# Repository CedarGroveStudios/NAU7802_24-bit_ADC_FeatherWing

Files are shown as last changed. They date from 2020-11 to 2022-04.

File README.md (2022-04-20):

# NAU7802_24-bit_ADC_FeatherWing

### Custom 24-bit load cell sensor ADC with dual analog inputs powered by CircuitPython.

[NAU7802 CircuitPython Driver: Class Description](https://github.com/CedarGroveStudios/NAU7802_24-bit_ADC_FeatherWing/blob/main/docs/pseudo%20readthedocs%20cedargrove_nau7802.pdf)

NAU7802 FeatherWing 16-SOIC (SMD) Version:



NAU7802 FeatherWing  16-DIP (THT) Version:



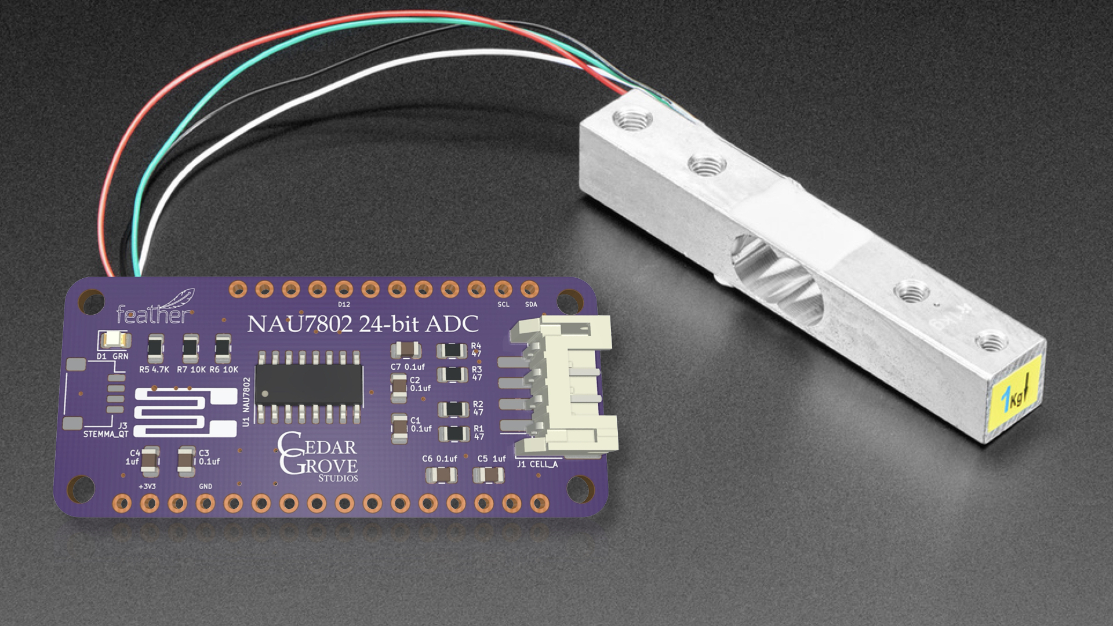
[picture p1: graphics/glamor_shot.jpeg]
NAU7802 FeatherWing


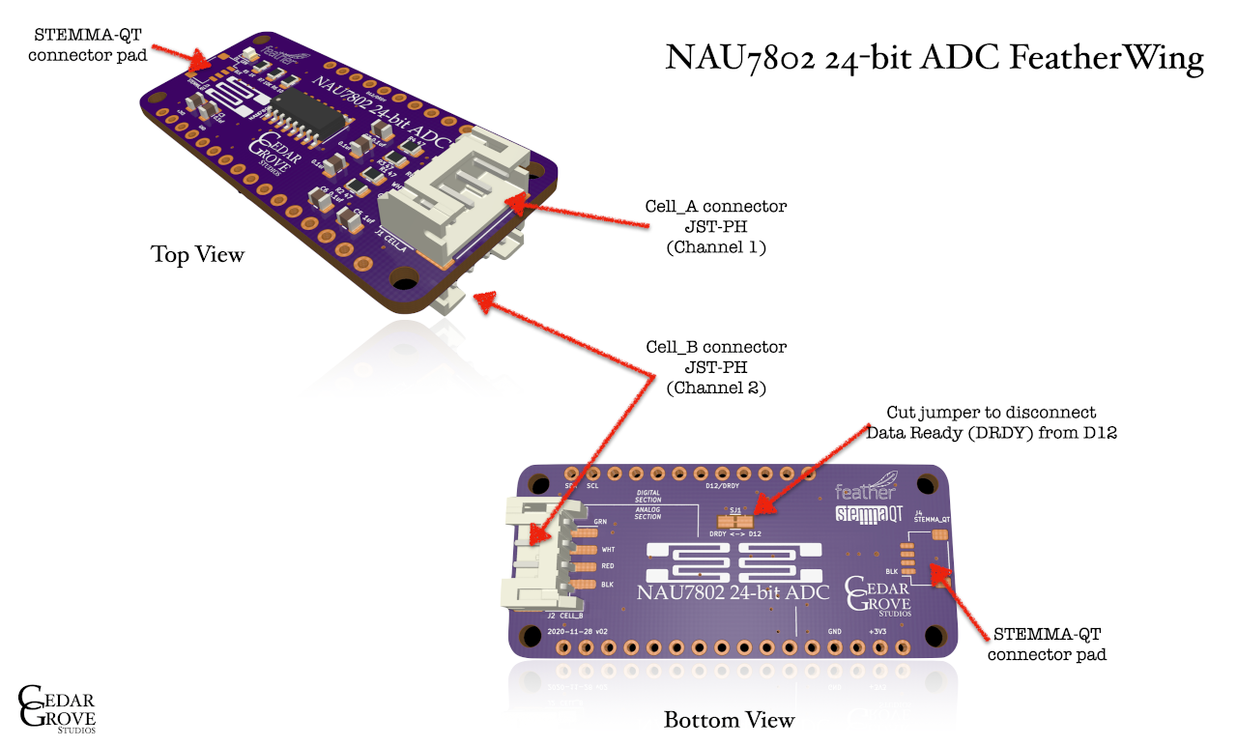
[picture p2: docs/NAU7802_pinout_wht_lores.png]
NAU7802 FeatherWing pinout


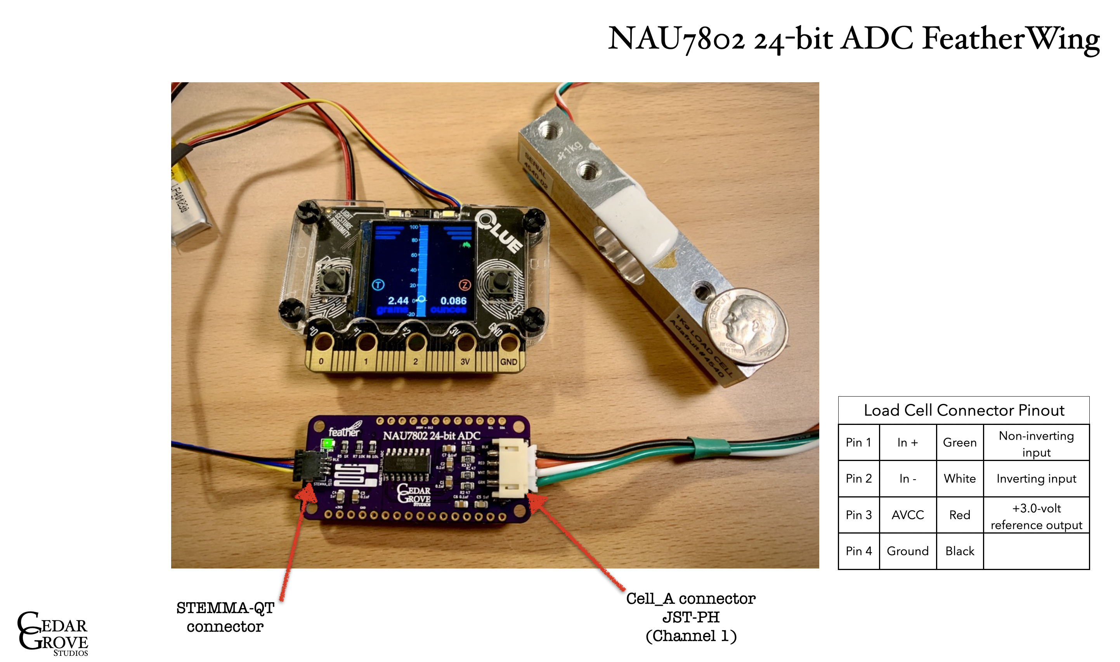
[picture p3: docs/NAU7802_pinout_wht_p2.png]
NAU7802 cable pinout


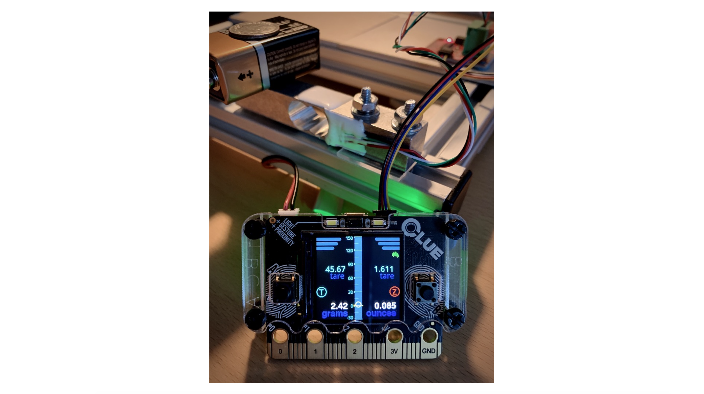
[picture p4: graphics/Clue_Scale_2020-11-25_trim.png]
Clue_Scale


Needing a calibration weight? The U.S. Mint coin specifications might have some information that could help -- if you have some spare change. https://www.usmint.gov/learn/coin-and-medal-programs/coin-specifications

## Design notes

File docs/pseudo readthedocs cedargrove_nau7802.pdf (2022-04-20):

## cedargrove_nau7802

A CircuitPython class for operating the Cedar Grove NAU7802 24-bit ADC load cell sensor FeatherWing.

The Cedar Grove NAU7802 FeatherWing is a high-precision 24-bit ADC with analog inputs designed for load cell Wheatstone bridge differential signals. The FeatherWing accepts input from up to two load cells, providing gain management, reference voltage selection, and channel calibration/offset functions. Applications include a variety of mass measurement and calculation devices from simple weighing scales to motor rotary torque calculations.

- Author(s): JG Cedar Grove Maker Studios

## Implementation Notes

### Hardware: Software and Dependencies:

- Adafruit CircuitPython firmware for the supported boards: https://github.com/adafruit/circuitpython/releases

Class representing the CedarGroveMaker NAU7802.

The primary function of the NAU7802 class. The read() function captures the latest 24-bit data acquired, sets the ADC data-availability status to False, and returns a signed integer value. The read() function does not check the ADC data-available status nor does it initiate a data acquisition cycle.

Determines the ADC data-availability status. Returns True when new data is available to read. The available() function does not initiate a data acquisition cycle.

class cedargrove_nau7802.NAU7802(*, i2c_bus, address=0x2A, active_channels=1)

Parameters: | • | i2c_bus – The I2C data and clock bus signals as defined in the host device’s board definition. Typical value is board.I2C() . No default value.
- address – The I2C bus address. Defaults to 0x2A (d42).
- active_channels – The maximum number of active analog differential input channels
| | used. The Cedar Grove NAU7802 FeatherWing supports either one or two input channels. Can only be a positive integer with a value of 1 or 2. Defaults to 1.

read()

available()

© Copyright 2021, 2022 Cedar Grove Maker Studios, Revision 1.3

Enable(start) or disable(stop) the internal analog and digital systems power. The device enters a low-power standby mode when disabled but preserves calibration information and maintains I2C communications. The device commences a 750msec power-up cycle when power=True and starts the acquisition cycle. The device will initiate a 10msec shutdown process when power=False. Returns True when power is enabled; False when disabled.

Perform the calibration procedure. Valid calibration modes are ‘INTERNAL’, ‘OFFSET’, and ‘GAIN’. Returns True if the calibration process was successful; False if an error occurred. For sensitive applications, calibration is recommended whenever the input channel is changed or when ambient conditions may cause measurement drift.

Resets all internal device registers and enables digital system power. Returns the power ready status Boolean value: True when the device is ready; False if not ready. All device registers are reset to the NAU7802 default settings including calibration offset and gain settings. It is not usually necessary to use the reset() function since it is executed as part of the class initialization process.

enable(power=True)

Parameters: | power – The power enable/disable state. Accepts a True or False Boolean value. Defaults to True (enable power).

calibrate(mode=‘INTERNAL’)

Parameters: | mode – The device calibration process to initiate. The following string values are accepted:
| ‘INTERNAL’ — Ignore analog input signals and calibrate the the input offset using an internal reference voltage. This is the default calibration setting.
| ‘OFFSET’ — Measure and store the external analog input offset for the selected channel. Analog input signals must be held at a zero input value during external offset calibration. Useful for determining the zero offset of an attached load cell bridge.
| ‘GAIN’ — Measure and store the external gain setting of the selected channel required for full-scale. Analog input signals must be held at the equivalent full- scale value during external gain calibration. Useful for determining the gain needed to calibrate a weighted load cell at its maximum sensor range.

reset()

A class property.

A class property.

A class property.

channel

Parameters: | channel – Change or read the numeric value of the currently selected external analog input channel. Valid external input channel numeric values are 1 or 2 representing the NAU7802 FeatherWing’s CELL_A and CELL_B, respectively. Selection of the second input channel requires active_channels=2 when the class is instantiated. The channel property defaults to 1.

ldo_voltage

Parameters: | ldo_voltage – Change or read the representative value of the currently selected internal low-dropout (LDO) regulator’s analog power and conversion reference voltage (AVCC). Digital supply voltage (DVCC) must be at least 0.3 volts greater than the selected ldo_voltage value. Valid string values are ‘2V4’, ‘2V7’, and ‘3V0’, representing 2.4, 2.7, and 3.0 volts. Defaults to ‘3V0’.

gain

Parameters: | gain – Change or read the value of the currently selected programmable gain amplifier (PGA) gain setting. Valid numeric values are 1, 2, 4, 8, 16, 31, 64, and 128. Defaults to
| 128.

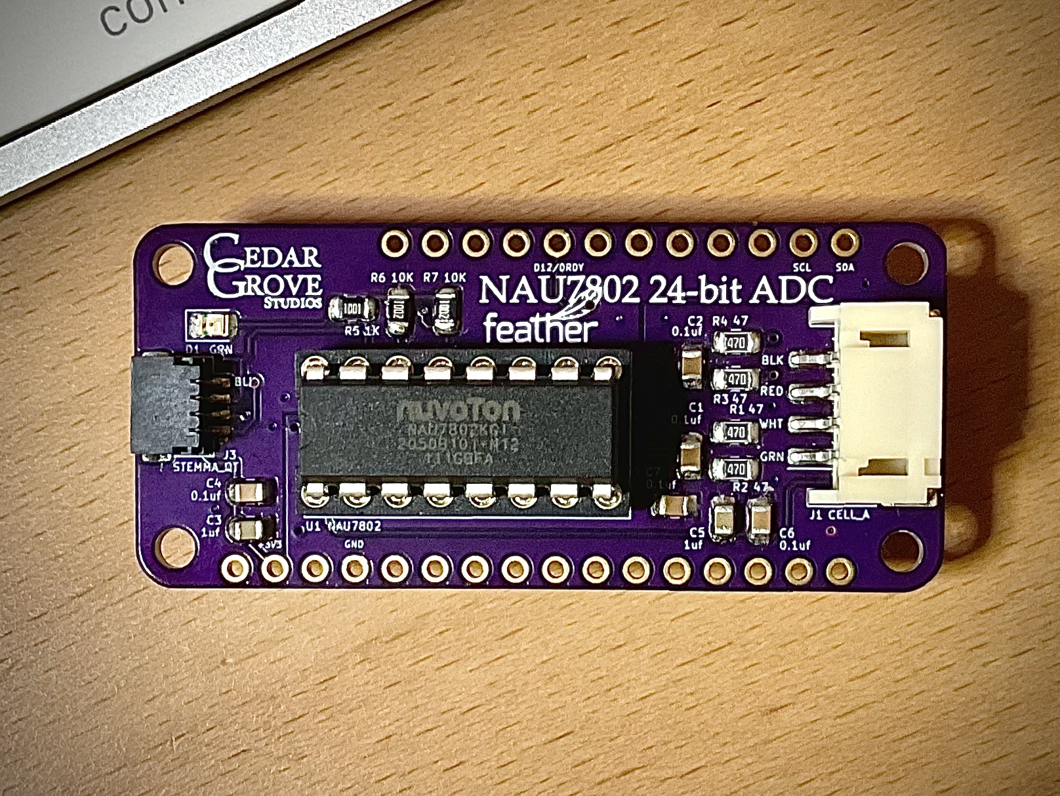
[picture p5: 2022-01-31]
docs/CG_NAU7802_FeatherWing_16-DIP.png

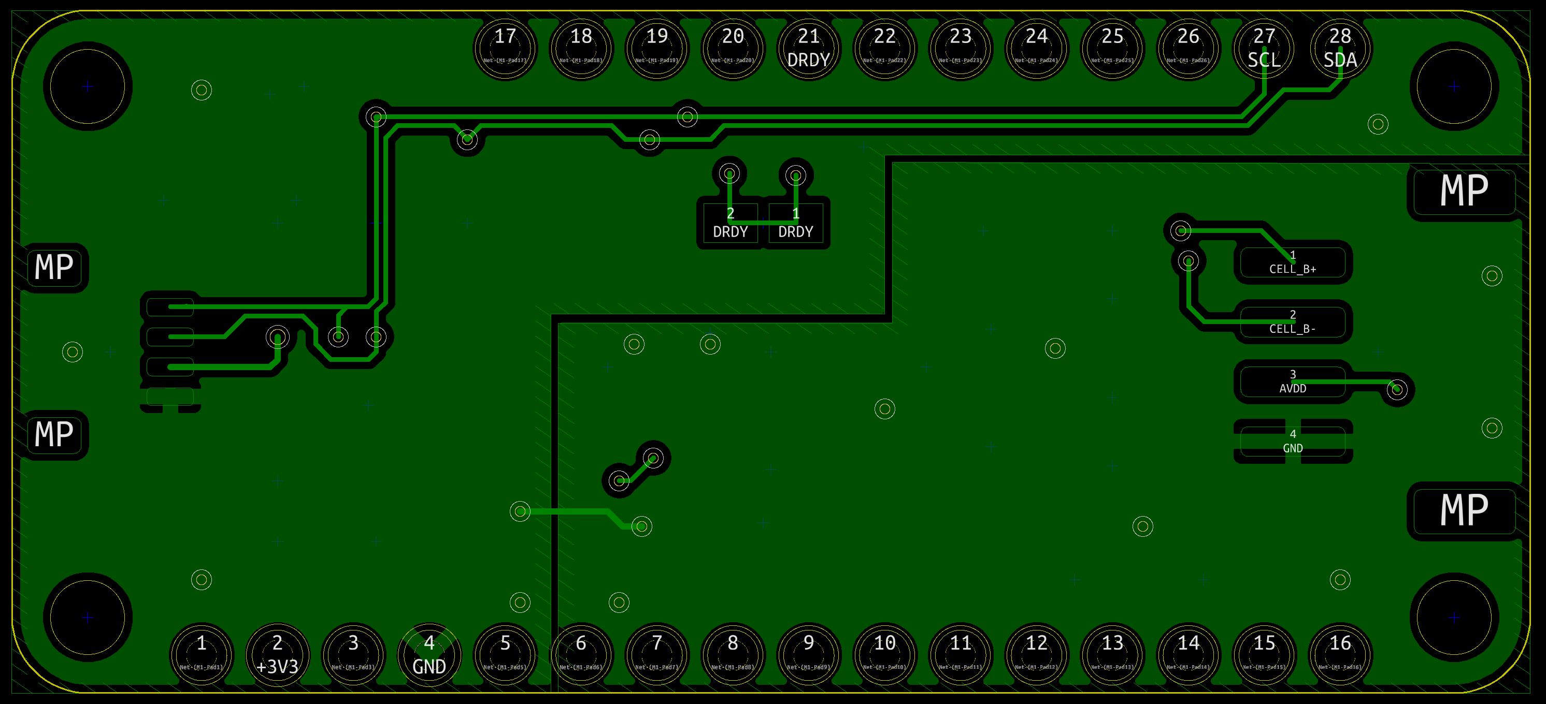
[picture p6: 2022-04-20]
pcb/pcb_bottom_copper.png

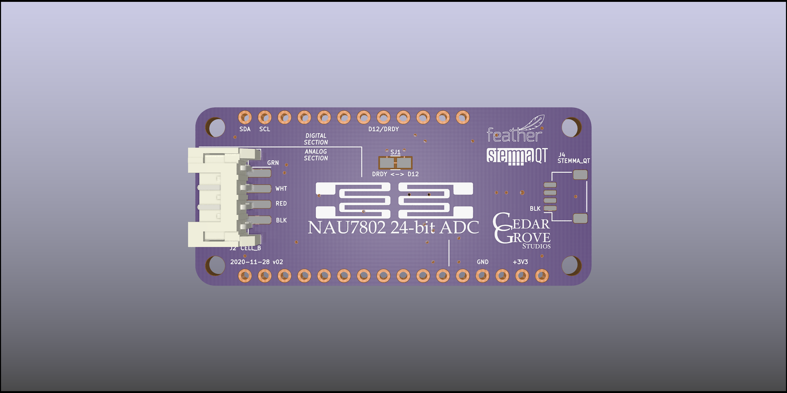
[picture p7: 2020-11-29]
pcb_DIP/NAU7802_Dual_24-bit_ADC_bot.png

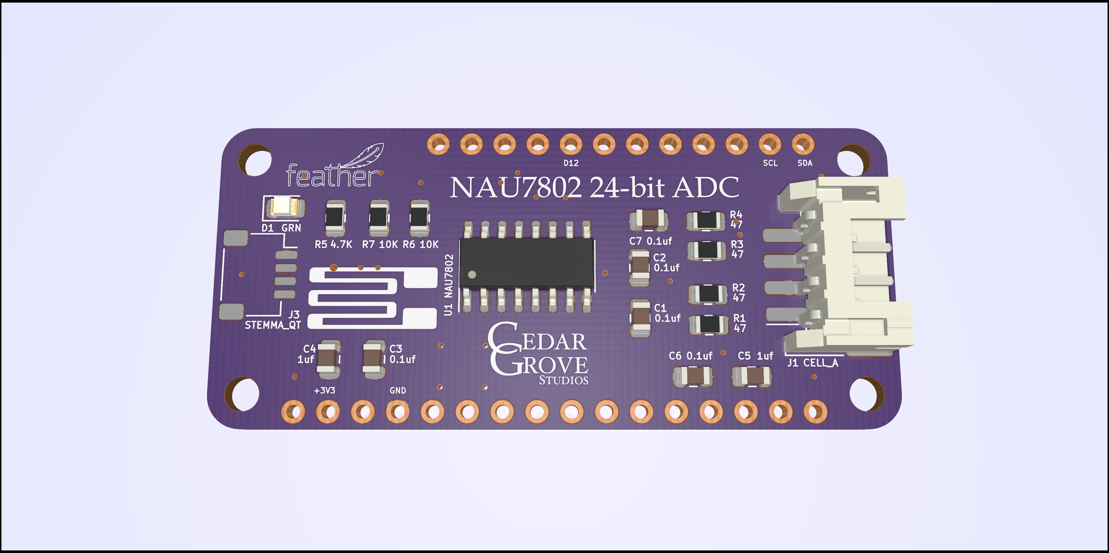
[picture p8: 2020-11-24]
graphics/NAU7802_Dual_24-bit_ADC.png

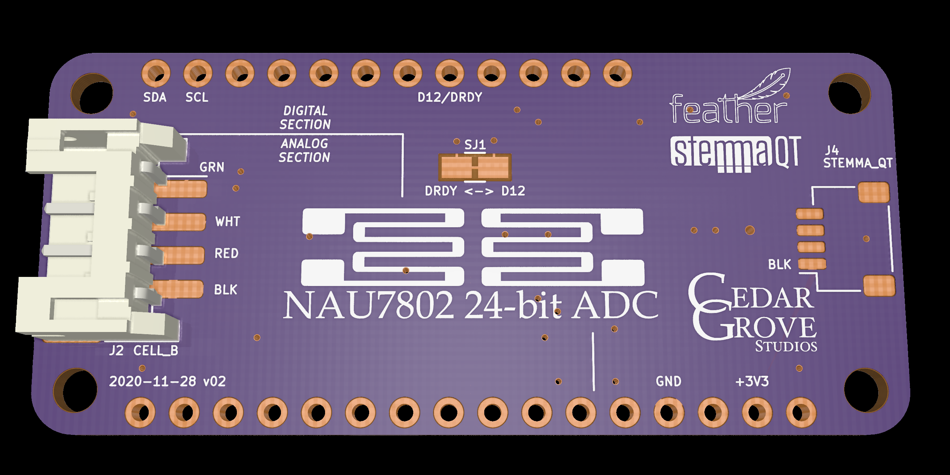
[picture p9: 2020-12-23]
graphics/NAU7802_Dual_24-bit_ADC_anno_2.png

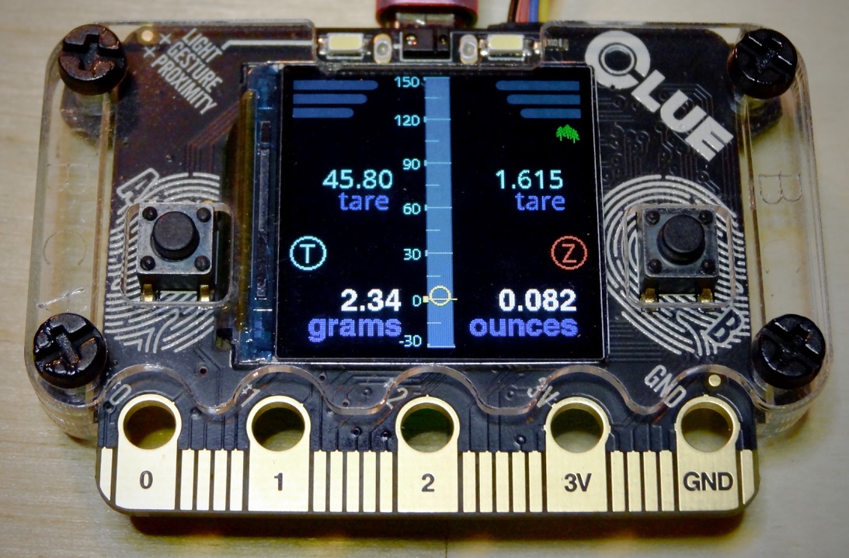
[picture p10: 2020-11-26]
graphics/Clue_Scale_2020-11-25.jpeg

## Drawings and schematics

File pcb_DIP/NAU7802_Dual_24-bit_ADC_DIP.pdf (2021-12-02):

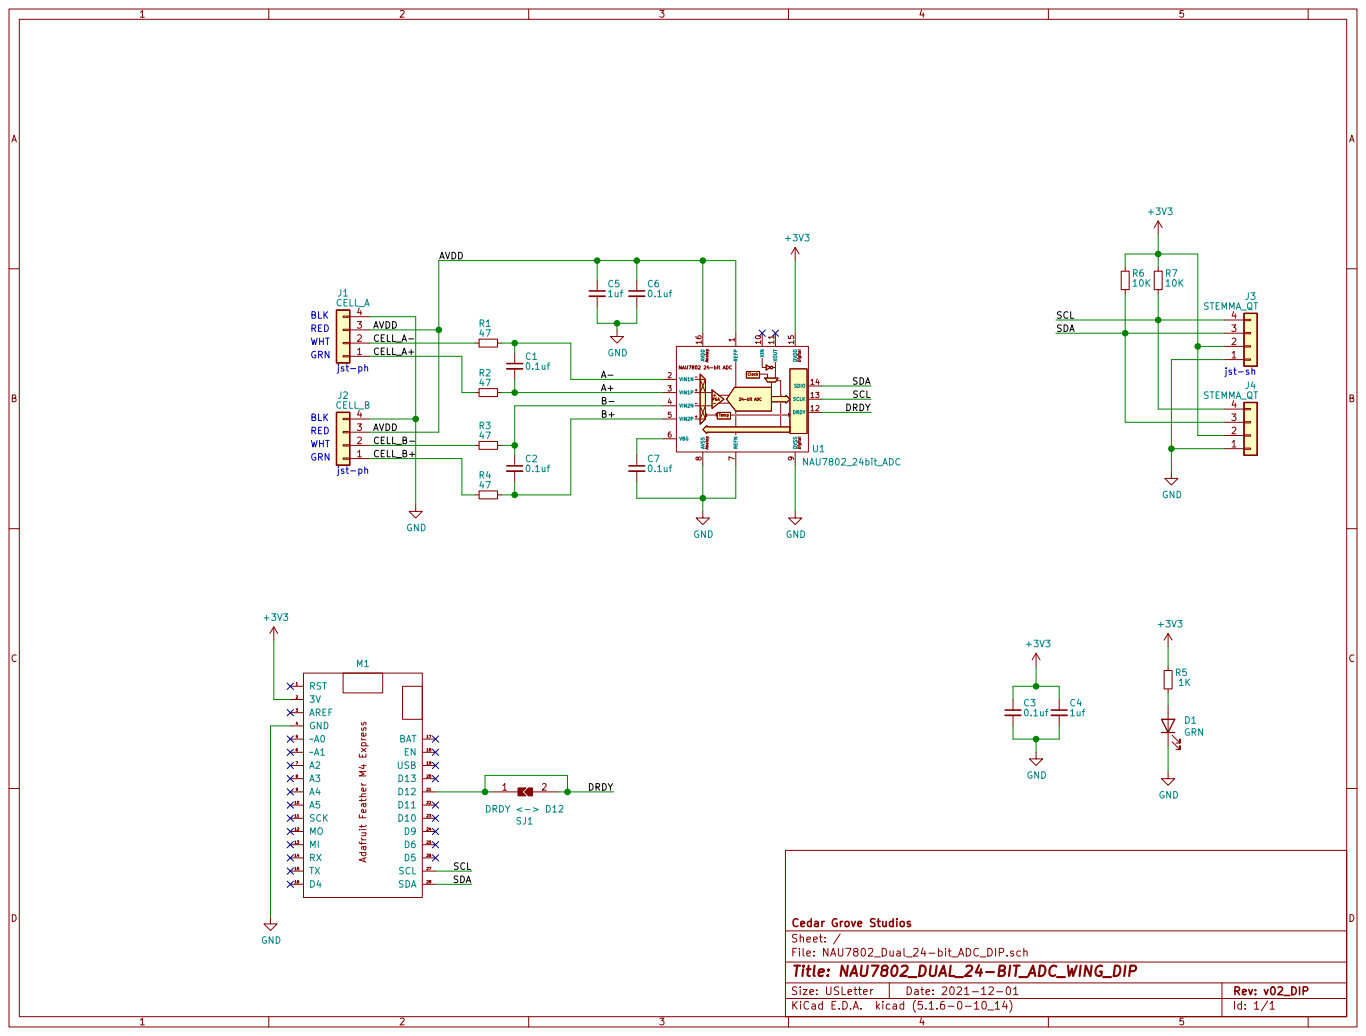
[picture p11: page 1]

SCL SDA WHT BLK GRN

File: NAU7802_Dual_24-bit_ADC_DIP.sch Sheet: / Cedar Grove Studios

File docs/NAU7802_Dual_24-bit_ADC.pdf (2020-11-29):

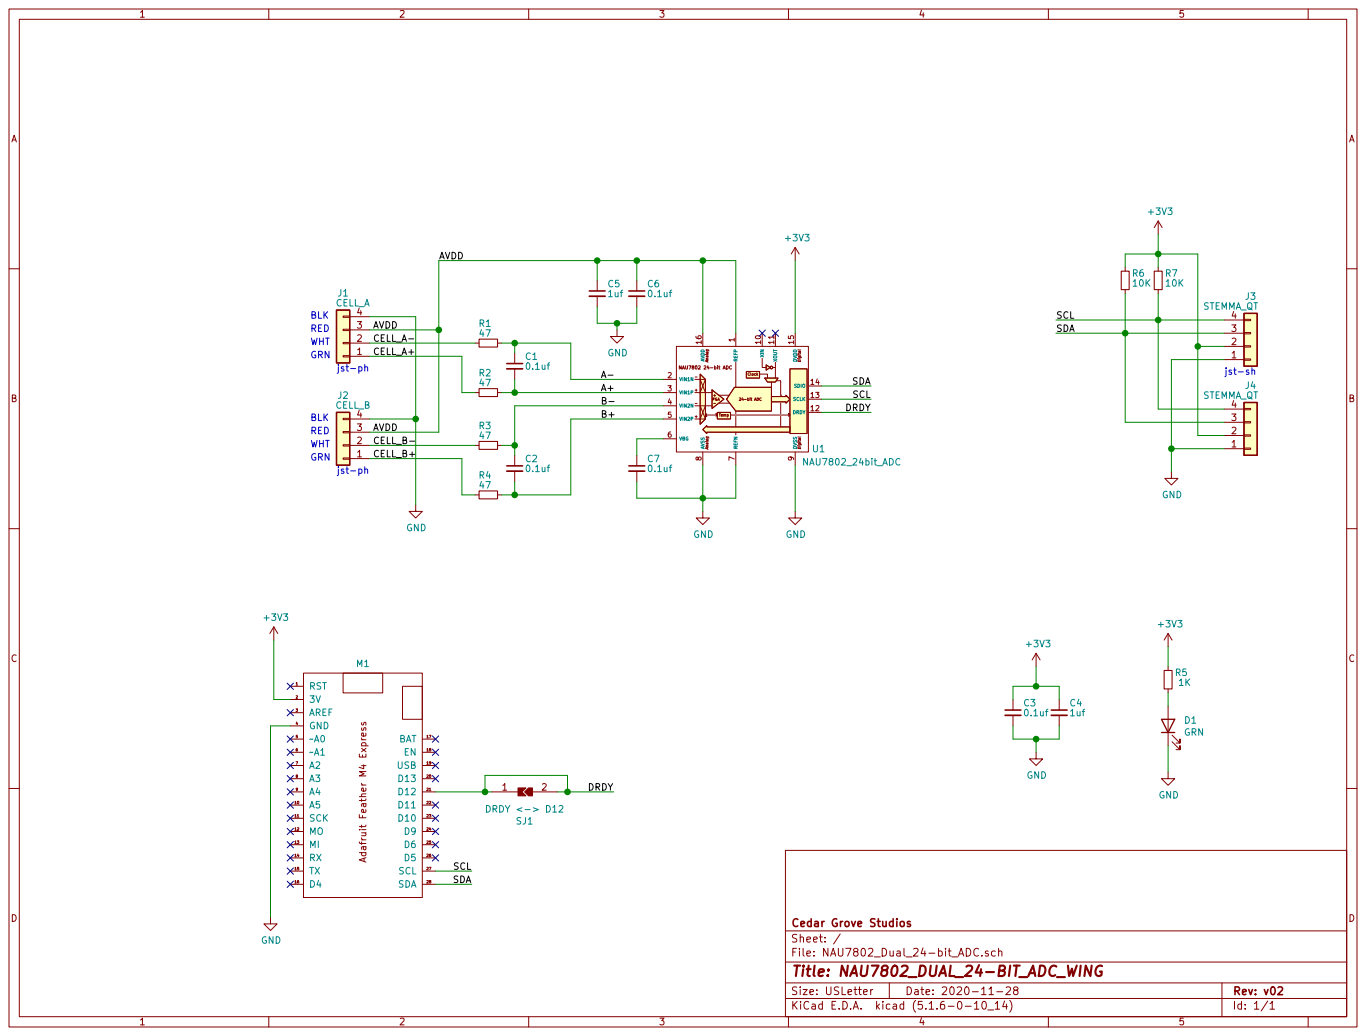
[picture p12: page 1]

SCL SDA WHT BLK GRN

File: NAU7802_Dual_24-bit_ADC.sch Sheet: / Cedar Grove Studios

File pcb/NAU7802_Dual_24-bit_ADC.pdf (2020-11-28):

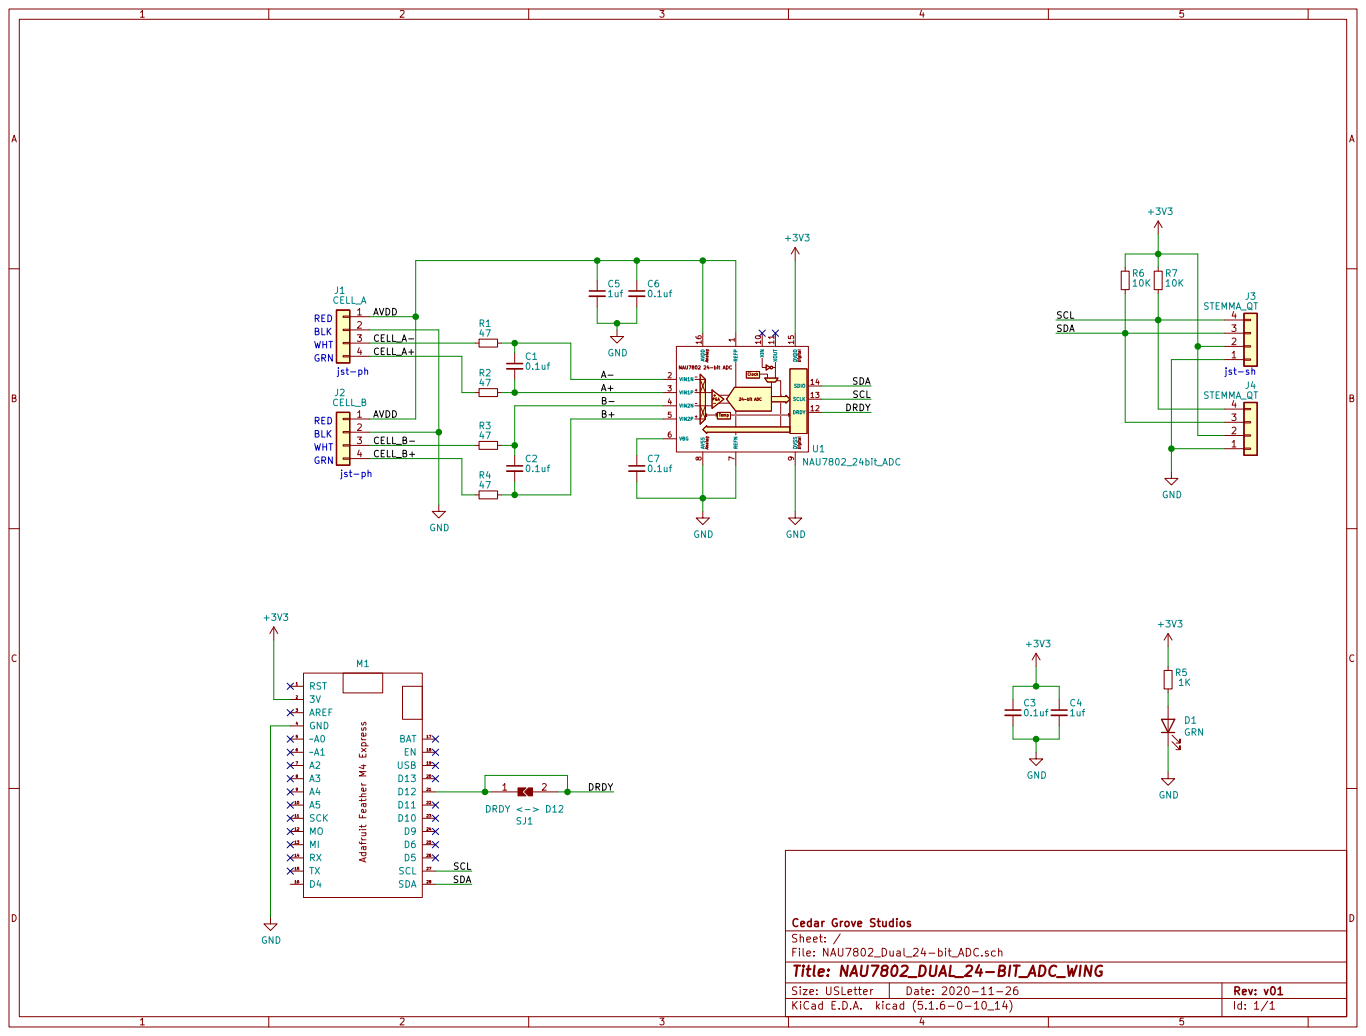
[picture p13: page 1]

CELL_B+ CELL_B- CELL_A+ CELL_A- AVDD WHT BLK GRN
RED

File: NAU7802_Dual_24-bit_ADC.sch Sheet: / Cedar Grove Studios

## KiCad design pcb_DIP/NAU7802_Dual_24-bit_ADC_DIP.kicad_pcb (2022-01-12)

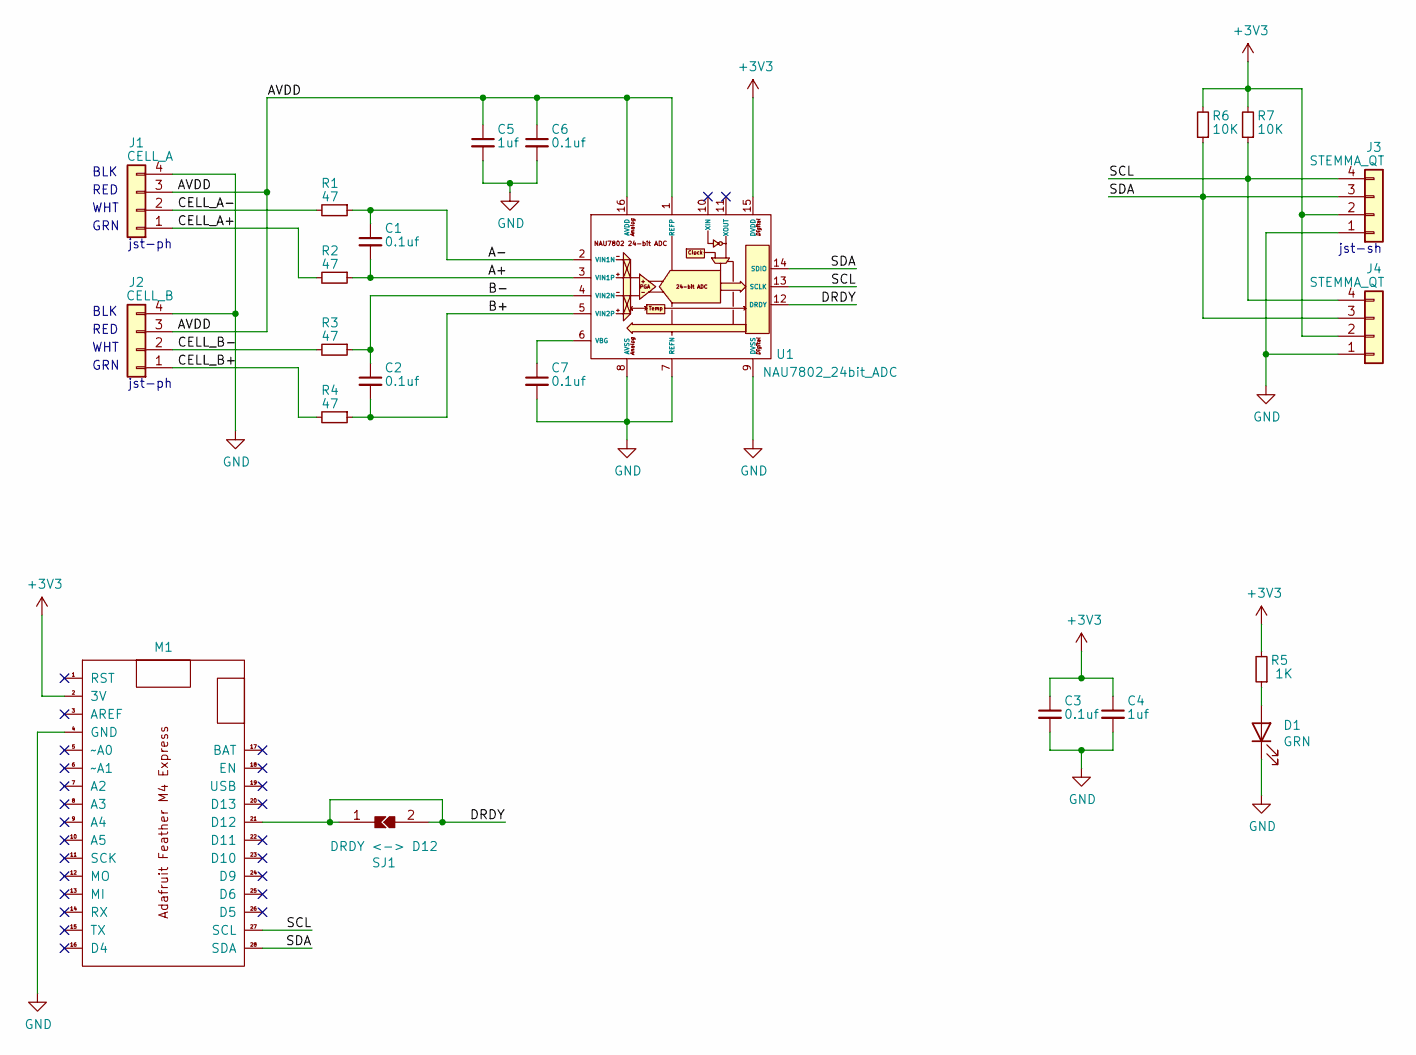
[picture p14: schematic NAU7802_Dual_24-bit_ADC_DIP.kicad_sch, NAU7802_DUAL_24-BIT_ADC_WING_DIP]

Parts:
C1, C2, C3, C6, C7: 0.1uf; C_0805_2012Metric
C4, C5: 1uf; C_0805_2012Metric
D1: GRN; LED_0805_2012Metric
J1: CELL_A; JST_PH_S4B-PH-SM4-TB_1x04-1MP_P2.00mm_Horizontal
J2: CELL_B; JST_PH_S4B-PH-SM4-TB_1x04-1MP_P2.00mm_Horizontal
J3, J4: STEMMA_QT; JST_SH_SM04B-SRSS-TB_1x04-1MP_P1.00mm_Horizontal
M1: Feather_M4_Express; Adafruit Feather
R1, R2, R3, R4: 47; R_0805_2012Metric
R5: 1K; R_0805_2012Metric
R6, R7: 10K; R_0805_2012Metric
SJ1: DRDY <-> D12; 0805_Solder_Jumper
U1: NAU7802_24bit_ADC; DIP-16_W7.62mm_Socket

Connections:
+3V3: C3.1, C4.1, J3.2, J4.2, M1.2 (3V), R5.2, R6.2, R7.2, U1.15 (DVDD)
/A+: C1.2, R2.1, U1.3 (VIN1P)
/A-: C1.1, R1.1, U1.2 (VIN1N)
/AVDD: C5.1, C6.1, J1.3, J2.3, U1.1 (REFP), U1.16 (AVDD)
/B+: C2.2, R4.1, U1.5 (VIN2P)
/B-: C2.1, R3.1, U1.4 (VIN2N)
/CELL_A+: J1.1, R2.2
/CELL_A-: J1.2, R1.2
/CELL_B+: J2.1, R4.2
/CELL_B-: J2.2, R3.2
/DRDY: M1.21 (D12), SJ1.1, SJ1.2, U1.12 (DRDY)
/SCL: J3.4, J4.4, M1.27 (SCL), R7.1, U1.13 (SCLK)
/SDA: J3.3, J4.3, M1.28 (SDA), R6.1, U1.14 (SDIO)
GND: C3.2, C4.2, C5.2, C6.2, C7.2, D1.1 (K), J1.4, J2.4, J3.1, J4.1, M1.4 (GND), U1.7 (REFN), U1.8 (AVSS), U1.9 (DVSS)
unnamed: C7.1, U1.6 (VBG)
unnamed: D1.2 (A), R5.1

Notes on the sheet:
RED
GRN
jst-sh
BLK
WHT
jst-ph

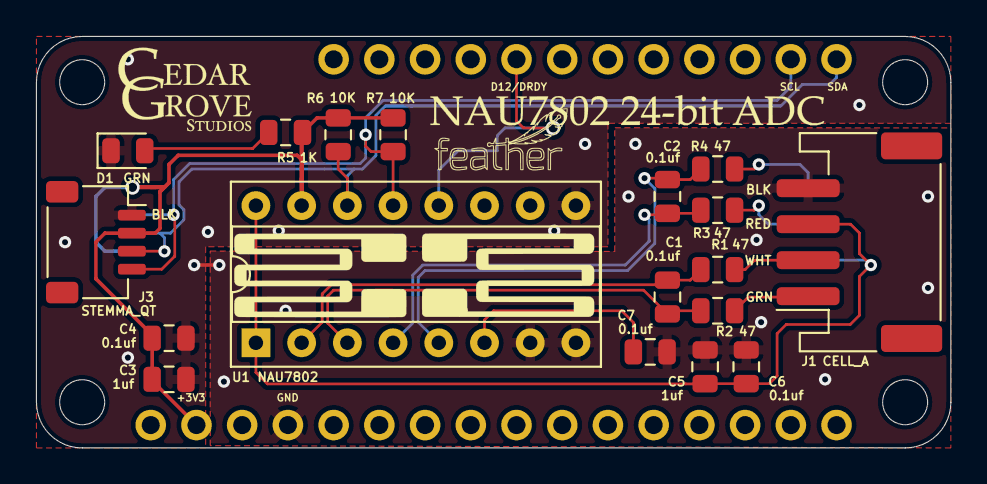
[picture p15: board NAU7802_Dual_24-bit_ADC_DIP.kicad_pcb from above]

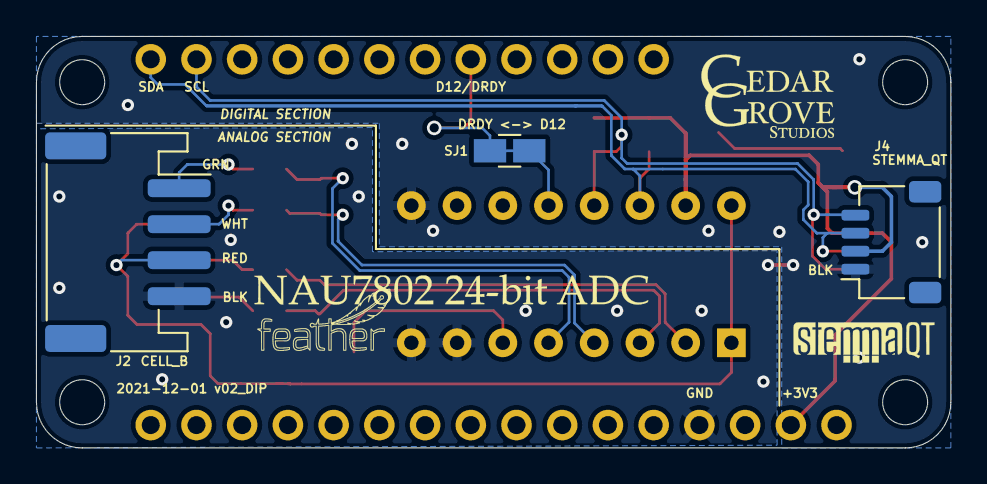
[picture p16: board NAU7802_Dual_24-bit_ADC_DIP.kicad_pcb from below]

Board: 2 copper layers, 50.8 x 22.9 mm, 23 parts (3 on the bottom side), 16 nets.

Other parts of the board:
REF: MountingHole_2.5mm

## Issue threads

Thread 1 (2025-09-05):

Error in read function.

robo32, 2025-09-05:
Why is everything shifted first 8 bits to the left. And at the end shiftend 7 places to the right. This should be 8 places to the right so:
self._adc_out = value / 256  # Restore to 24-bit signed integer value

I would do it even simpler like this:

        adc = (self._adc_out_2 << 16) | (self._adc_out_1 << 8) | self._adc_out_0

        # Sign-extend 24-bit to Python int
        if adc & 0x800000:  # if sign bit set
            adc -= 1 << 24

        return adc = self._adc_out

Closed 2025-09-06.

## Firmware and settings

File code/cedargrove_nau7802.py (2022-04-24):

# SPDX-FileCopyrightText: Copyright (c) 2022 JG for Cedar Grove Maker Studios
#
# SPDX-License-Identifier: MIT
"""
`cedargrove_nau7802`
================================================================================

A CircuitPython driver class for the NAU7802 24-bit ADC. Supports dual analog
inputs.


* Author(s): JG

Implementation Notes
--------------------

**Hardware:**

* `NAU7802 FeatherWing; OSH Park project (16-SOIC version)
  <https://oshpark.com/shared_projects/qFvEU3Bn>`_
* `NAU7802 FeatherWing; OSH Park project (16-DIP version)
  <https://oshpark.com/shared_projects/ZfryHYnc>`_
* `SparkFun Quicc Scale (single channel) <https://www.sparkfun.com/products/15242>`_

**Software and Dependencies:**

* Adafruit CircuitPython firmware for the supported boards:
  https://circuitpython.org/downloads

* Adafruit's Bus Device library: https://github.com/adafruit/Adafruit_CircuitPython_BusDevice
* Adafruit's Register library: https://github.com/adafruit/Adafruit_CircuitPython_Register
"""

import time
import struct

from adafruit_bus_device.i2c_device import I2CDevice
from adafruit_register.i2c_struct import ROUnaryStruct

# from adafruit_register.i2c_struct   import UnaryStruct
from adafruit_register.i2c_bits import RWBits
from adafruit_register.i2c_bits import ROBits
from adafruit_register.i2c_bit import RWBit
from adafruit_register.i2c_bit import ROBit

__version__ = "0.0.0-auto.0"
__repo__ = "https://github.com/CedarGroveStudios/Cedargrove_CircuitPython_NAU7802.git"

# DEVICE REGISTER MAP
_PU_CTRL = 0x00  # Power-Up Control RW
_CTRL1 = 0x01  # Control 1 RW
_CTRL2 = 0x02  # Control 2 RW
_ADCO_B2 = 0x12  # ADC_OUT[23:16] R-
_ADCO_B1 = 0x13  # ADC_OUT[16: 8] R-
_ADCO_B0 = 0x14  # ADC_OUT[ 7: 0] R-
_OTP_B1 = 0x15  # OTP[15: 8] R-
_ADC = 0x15  # ADC Control -W
_OTP_B0 = 0x16  # OTP[ 7: 0] R-
_PGA = 0x1B  # Programmable Gain Amplifier  RW
_PWR_CTRL = 0x1C  # Power Control  RW
_REV_ID = 0x1F  # Chip Revision ID  R-

# pylint: disable=too-few-public-methods
class LDOVoltage:
    """Internal low-dropout voltage regulator settings."""

    LDO_3V0 = 0x5  # LDO 3.0 volts; _CTRL1[5:3] = 5
    LDO_2V7 = 0x6  # LDO 2.7 volts; _CTRL1[5:3] = 6
    LDO_2V4 = 0x7  # LDO 2.4 volts; _CTRL1[5:3] = 7


class Gain:
    """Analog differential amplifier gain settings."""

    GAIN_X1 = 0x0  # Gain X1; _CTRL1[2:0] = 0 (chip default)
    GAIN_X2 = 0x1  # Gain X1; _CTRL1[2:0] = 1
    GAIN_X4 = 0x2  # Gain X1; _CTRL1[2:0] = 2
    GAIN_X8 = 0x3  # Gain X1; _CTRL1[2:0] = 3
    GAIN_X16 = 0x4  # Gain X1; _CTRL1[2:0] = 4
    GAIN_X32 = 0x5  # Gain X1; _CTRL1[2:0] = 5
    GAIN_X64 = 0x6  # Gain X1; _CTRL1[2:0] = 6
    GAIN_X128 = 0x7  # Gain X1; _CTRL1[2:0] = 7


class ConversionRate:
    """ADC conversion rate settings."""

    RATE_10SPS = 0x0  # 10 samples/sec; _CTRL2[6:4] = 0 (chip default)
    RATE_20SPS = 0x1  # 20 samples/sec; _CTRL2[6:4] = 1
    RATE_40SPS = 0x2  # 40 samples/sec; _CTRL2[6:4] = 2
    RATE_80SPS = 0x3  # 80 samples/sec; _CTRL2[6:4] = 3
    RATE_320SPS = 0x7  # 320 samples/sec; _CTRL2[6:4] = 7


class CalibrationMode:
    """Calibration mode state settings."""

    INTERNAL = 0x0  # Offset Calibration Internal; _CTRL2[1:0] = 0 (chip default)
    OFFSET = 0x2  # Offset Calibration System;   _CTRL2[1:0] = 2
    GAIN = 0x3  # Gain   Calibration System;   _CTRL2[1:0] = 3


class NAU7802:
    """The primary NAU7802 class."""

    # pylint: disable=too-many-instance-attributes
    def __init__(self, i2c_bus, address=0x2A, active_channels=1):
        """Instantiate NAU7802; LDO 3v0 volts, gain 128, 10 samples per second
        conversion rate, disabled ADC chopper clock, low ESR caps, and PGA output
        stabilizer cap if in single channel mode. Returns True if successful."""
        self.i2c_device = I2CDevice(i2c_bus, address)
        if not self.reset():
            raise RuntimeError("NAU7802 device could not be reset")
        if not self.enable(True):
            raise RuntimeError("NAU7802 device could not be enabled")
        self.ldo_voltage = "3V0"  # 3.0-volt internal analog power (AVDD)
        self._pu_ldo_source = True  # Internal analog power (AVDD)
        self.gain = 128  # X128
        self._c2_conv_rate = ConversionRate.RATE_10SPS  # 10 SPS; default
        self._adc_chop_clock = 0x3  # 0x3 = Disable ADC chopper clock
        self._pga_ldo_mode = 0x0  # 0x0 = Use low ESR capacitors
        self._act_channels = active_channels
        # 0x1 = Enable PGA out stabilizer cap for single channel use
        self._pc_cap_enable = 0x1
        if self._act_channels == 2:
            # 0x0 = Disable PGA out stabilizer cap for dual channel use
            self._pc_cap_enable = 0x0
        self._calib_mode = None  # Initialize for later use
        self._adc_out = None  # Initialize for later use

    # DEFINE I2C DEVICE BITS, NYBBLES, BYTES, AND REGISTERS
    # Chip Revision  R-
    _rev_id = ROBits(4, _REV_ID, 0, 1, False)
    # Register Reset  (RR)  RW
    _pu_reg_reset = RWBit(_PU_CTRL, 0, 1, False)
    # Power-Up Digital Circuit  (PUD) RW
    _pu_digital = RWBit(_PU_CTRL, 1, 1, False)
    # Power-Up Analog Circuit  (PUA) RW
    _pu_analog = RWBit(_PU_CTRL, 2, 1, False)
    # Power-Up Ready Status  (PUR) R-
    _pu_ready = ROBit(_PU_CTRL, 3, 1, False)
    # Power-Up Conversion Cycle Start  (CS) RW
    _pu_cycle_start = RWBit(_PU_CTRL, 4, 1, False)
    # Power-Up Cycle Ready  (CR) R-
    _pu_cycle_ready = ROBit(_PU_CTRL, 5, 1, False)
    # Power-Up AVDD Source  ADDS) RW
    _pu_ldo_source = RWBit(_PU_CTRL, 7, 1, False)
    # Control_1 Gain  (GAINS) RW
    _c1_gains = RWBits(3, _CTRL1, 0, 1, False)
    # Control_1 LDO Voltage  (VLDO) RW
    _c1_vldo_volts = RWBits(3, _CTRL1, 3, 1, False)
    # Control_2 Calibration Mode  (CALMOD) RW
    _c2_cal_mode = RWBits(2, _CTRL2, 0, 1, False)
    # Control_2 Calibration Start  (CALS) RW
    _c2_cal_start = RWBit(_CTRL2, 2, 1, False)
    # Control_2 Calibration Error (CAL_ERR) RW
    _c2_cal_error = RWBit(_CTRL2, 3, 1, False)
    # Control_2 Conversion Rate  (CRS) RW
    _c2_conv_rate = RWBits(3, _CTRL2, 4, 1, False)
    # Control_2 Channel Select  (CHS) RW
    _c2_chan_select = RWBit(_CTRL2, 7, 1, False)
    # ADC Result Output  MSByte R-
    _adc_out_2 = ROUnaryStruct(_ADCO_B2, ">B")
    # ADC Result Output  MidSByte R-
    _adc_out_1 = ROUnaryStruct(_ADCO_B1, ">B")
    # ADC Result Output  LSByte R-
    _adc_out_0 = ROUnaryStruct(_ADCO_B0, ">B")
    # ADC Chopper Clock Frequency Select  -W
    _adc_chop_clock = RWBits(2, _ADC, 4, 1, False)
    # PGA Stability/Accuracy Mode (LDOMODE) RW
    _pga_ldo_mode = RWBit(_PGA, 6, 1, False)
    # Power_Ctrl PGA Capacitor (PGA_CAP_EN) RW
    _pc_cap_enable = RWBit(_PWR_CTRL, 7, 1, False)

    @property
    def chip_revision(self):
        """The chip revision code."""
        return self._rev_id

    @property
    def channel(self):
        "Selected channel number (1 or 2)."
        return self._c2_chan_select + 1
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

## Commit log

2020-11-24 initial repo load
    [NAU7802_Dual_24-bit_ADC-B_Cu.gbr, NAU7802_Dual_24-bit_ADC-B_Mask.gbr, NAU7802_Dual_24-bit_ADC-B_SilkS.gbr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]
2020-11-27 update for 2-channel operation
    [NAU7802_Dual_24-bit_ADC-B_Cu.gbr, NAU7802_Dual_24-bit_ADC-B_Mask.gbr, NAU7802_Dual_24-bit_ADC-B_SilkS.gbr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]
2020-11-28 update PCB silk design
    [NAU7802_Dual_24-bit_ADC-B_Cu.gbr, NAU7802_Dual_24-bit_ADC-B_Mask.gbr, NAU7802_Dual_24-bit_ADC-B_SilkS.gbr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]
2020-11-29 update PCB design
    [NAU7802_Dual_24-bit_ADC-B_Cu.gbr, NAU7802_Dual_24-bit_ADC-B_Mask.gbr, NAU7802_Dual_24-bit_ADC-B_SilkS.gbr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]
2020-12-30 add calibrate method
2021-01-07 update calibration method
2021-01-10 update driver for channel switch settling time; continue work on examples
2021-01-10 update driver with channel select settling delay; continue work on examples
2021-01-11 update driver and examples
2021-12-02 refactor SMD wing to accept ADC DIP pkg
    [NAU7802_Dual_24-bit_ADC_DIP-B_Cu.gbr, NAU7802_Dual_24-bit_ADC_DIP-B_Mask.gbr, NAU7802_Dual_24-bit_ADC_DIP-B_SilkS.gbr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]
2021-12-02 refactor wing for NAU7802 ADC DIP package
    [NAU7802_Dual_24-bit_ADC_DIP-B_Cu.gbr, NAU7802_Dual_24-bit_ADC_DIP-B_Mask.gbr, NAU7802_Dual_24-bit_ADC_DIP-B_SilkS.gbr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]
2021-12-07 add DIP package version
    [NAU7802_Dual_24-bit_ADC_DIP-B_Cu.gbr, NAU7802_Dual_24-bit_ADC_DIP-B_Mask.gbr, NAU7802_Dual_24-bit_ADC_DIP-B_SilkS.gbr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]
2022-01-12 update to newest kicad version
    [NAU7802_Dual_24-bit_ADC_DIP.kicad_pcb, NAU7802_Dual_24-bit_ADC_DIP.kicad_sch]
2022-04-20 update with PCB copper images
2022-04-20 improve calibration performance
2022-04-24 update NAU7802 driver class
